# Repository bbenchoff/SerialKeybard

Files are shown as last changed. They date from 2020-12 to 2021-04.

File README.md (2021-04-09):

# Serial Keyboard

It's a keyboard that transmits serial. Or it's a 256-key keyboard, using 18 keys. Something like that. The main thing is that it transmits any serial byte.

## Notice

This repo contains a few files, but is mostly geared towards an unoptimized build with the internal structure consisting of five(!) different PCBs. The SerialKeyboard.brd is just a 18-key keyboard with diodes. The DisplayCarrier.brd is an interposer between the display and Motherboard.brd, which is the only thing with active electronics. There's also an Arduino in there and the front panel, which makes for a grand total of five different PCBs in this project.

I have started work on a simplified version, MasterBoard.brd, which would combine this all into one single circuit board. This work is not completed.

If someone can find me a source of 2U 'Transmit' keycaps, I'll get right on that.

Oh yeah, I noticed this repo was named 'SerialKeybard', but it's too late to fix it now.

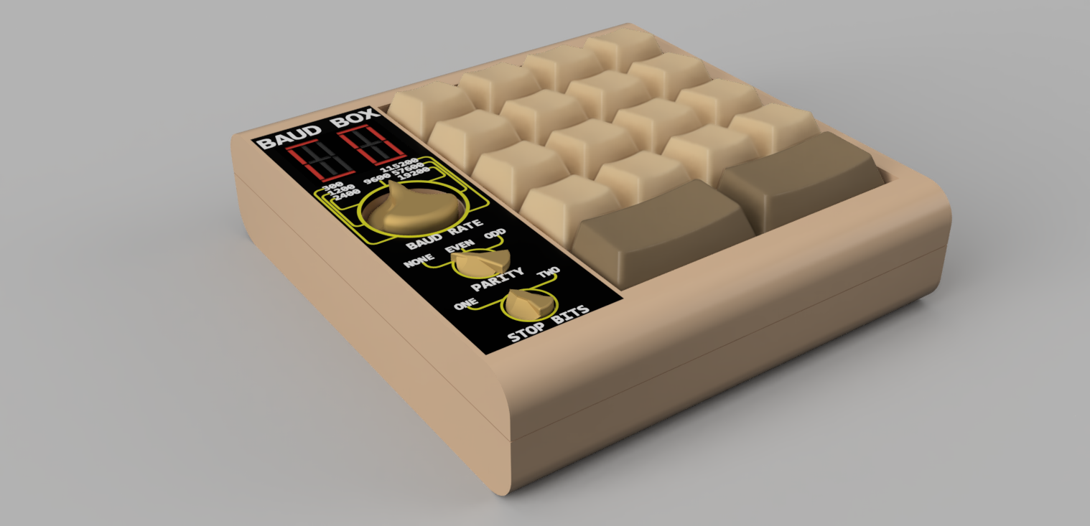
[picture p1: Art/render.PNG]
render


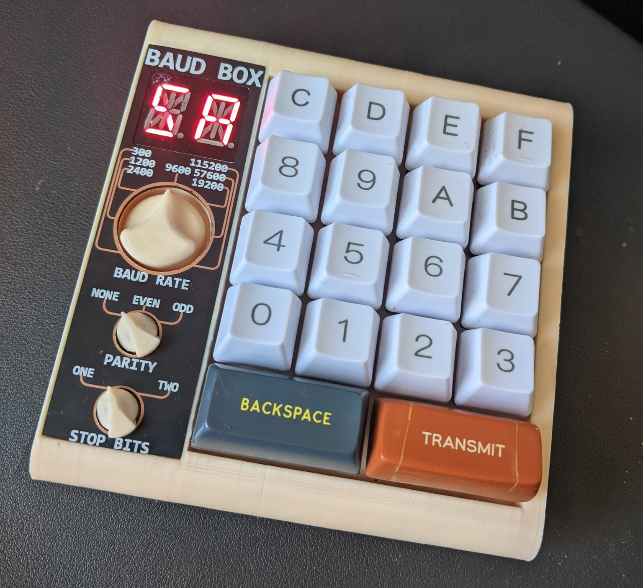
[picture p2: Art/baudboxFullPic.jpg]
full pic


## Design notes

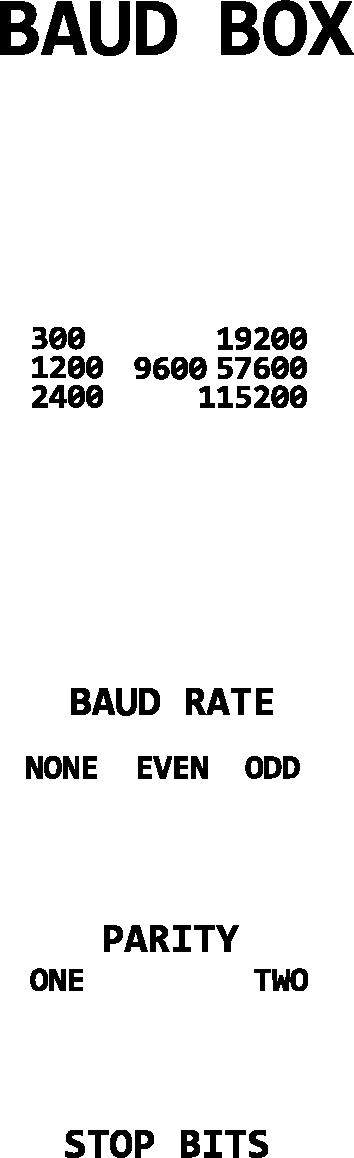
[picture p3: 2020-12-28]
Art/PanelText.bmp

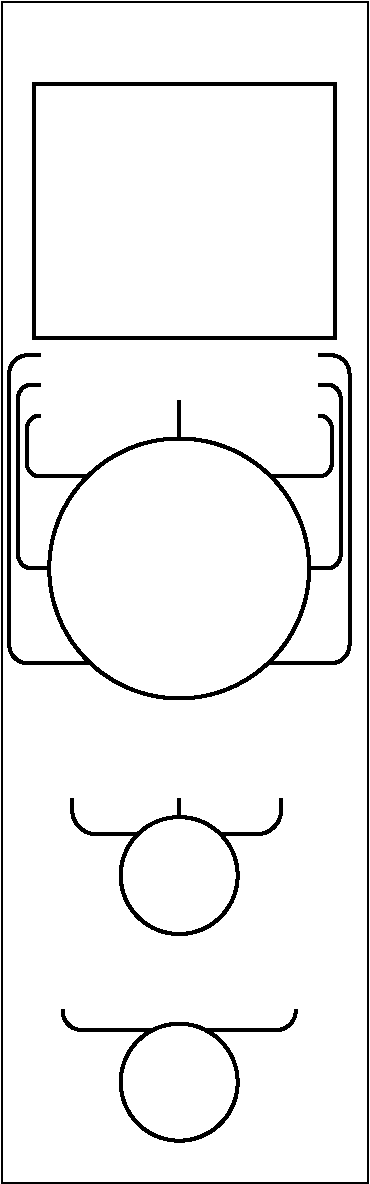
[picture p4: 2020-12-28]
Art/PanelCopper.bmp

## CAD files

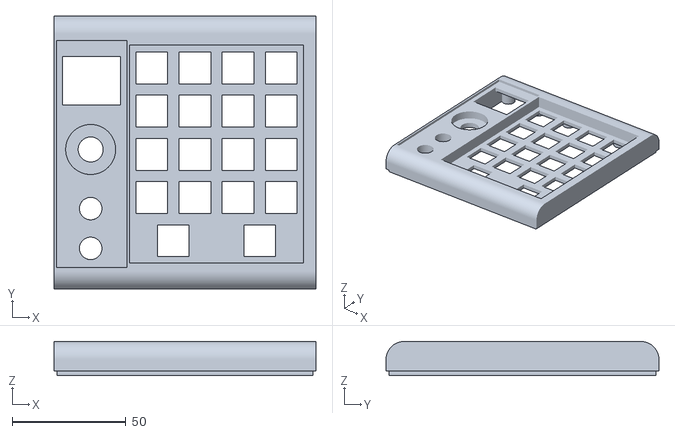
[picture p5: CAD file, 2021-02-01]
3D/Top.stl
115.2 x 120.1 x 15.0

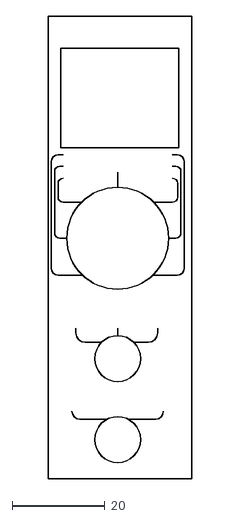
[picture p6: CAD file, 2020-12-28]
Art/PanelCopper.dxf
31.0 x 100.0

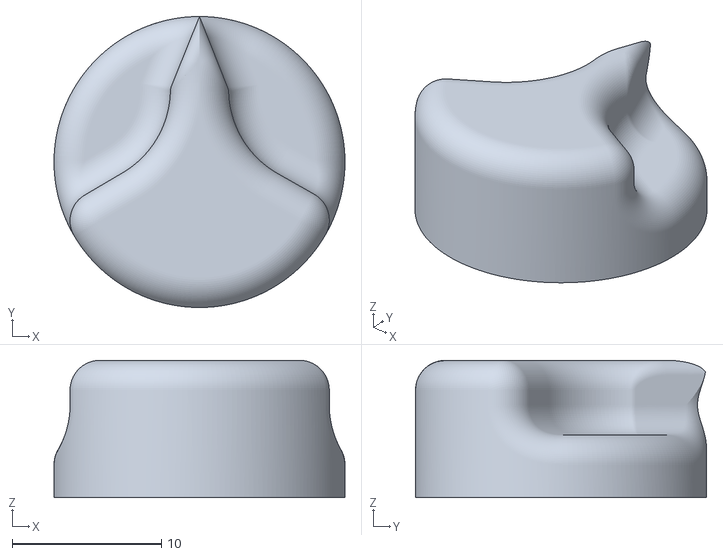
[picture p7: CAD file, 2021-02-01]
3D/BigKnob.stl
19.5 x 19.5 x 9.21

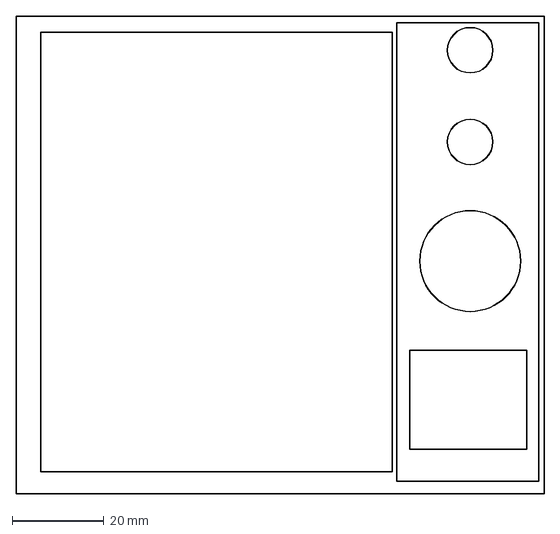
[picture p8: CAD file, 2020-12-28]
Art/PanelOutline.dxf
115.2 x 104.1 mm

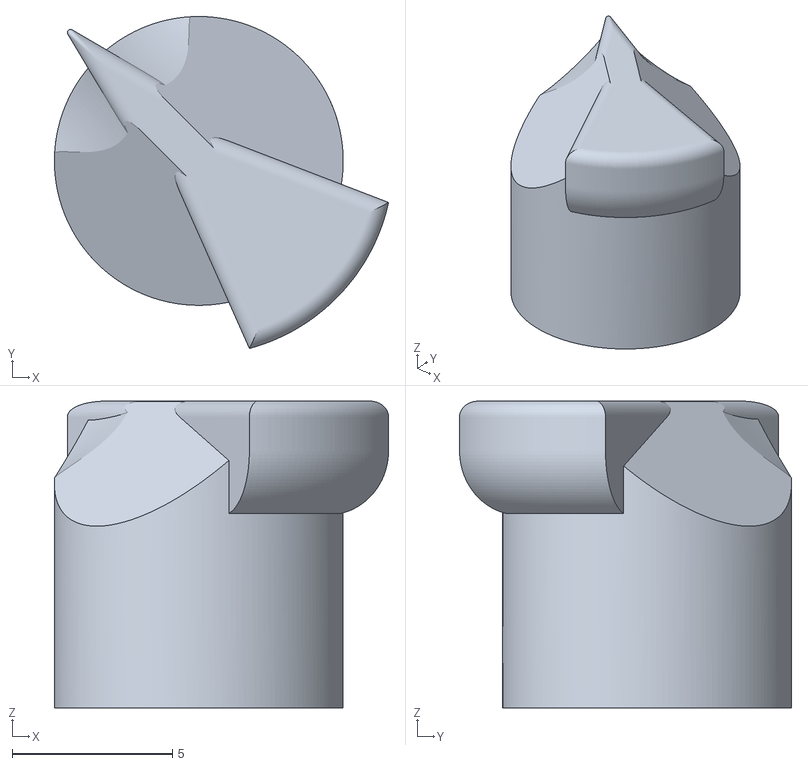
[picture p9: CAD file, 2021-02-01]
3D/SmallKnob.stl
10.4 x 10.3 x 9.57

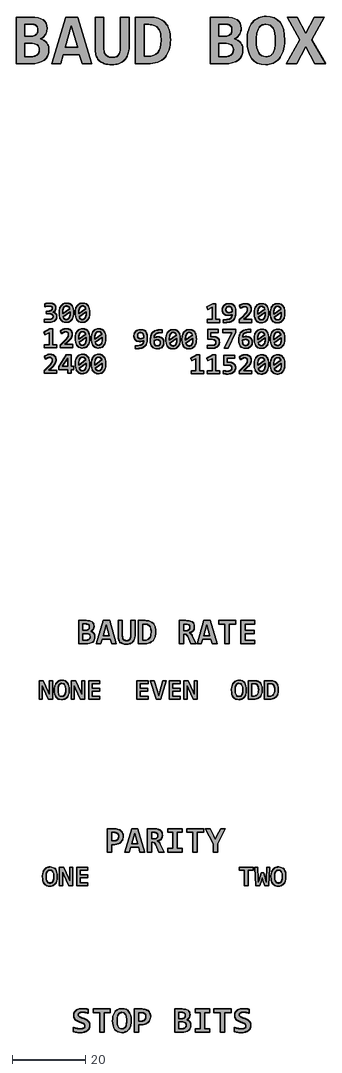
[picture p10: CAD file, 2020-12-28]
Art/PanelText.dxf
84.7 x 277.7

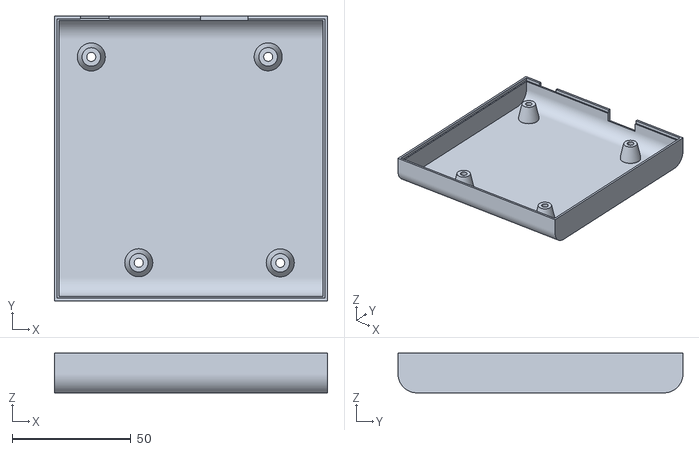
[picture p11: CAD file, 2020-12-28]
3D/Bottom.stl
115.2 x 120.1 x 16.8

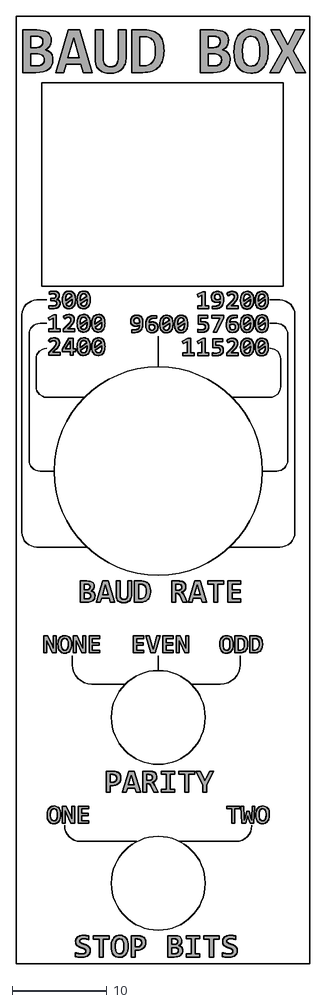
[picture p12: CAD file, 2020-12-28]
Art/FrontPanel.dxf
31.0 x 100.0

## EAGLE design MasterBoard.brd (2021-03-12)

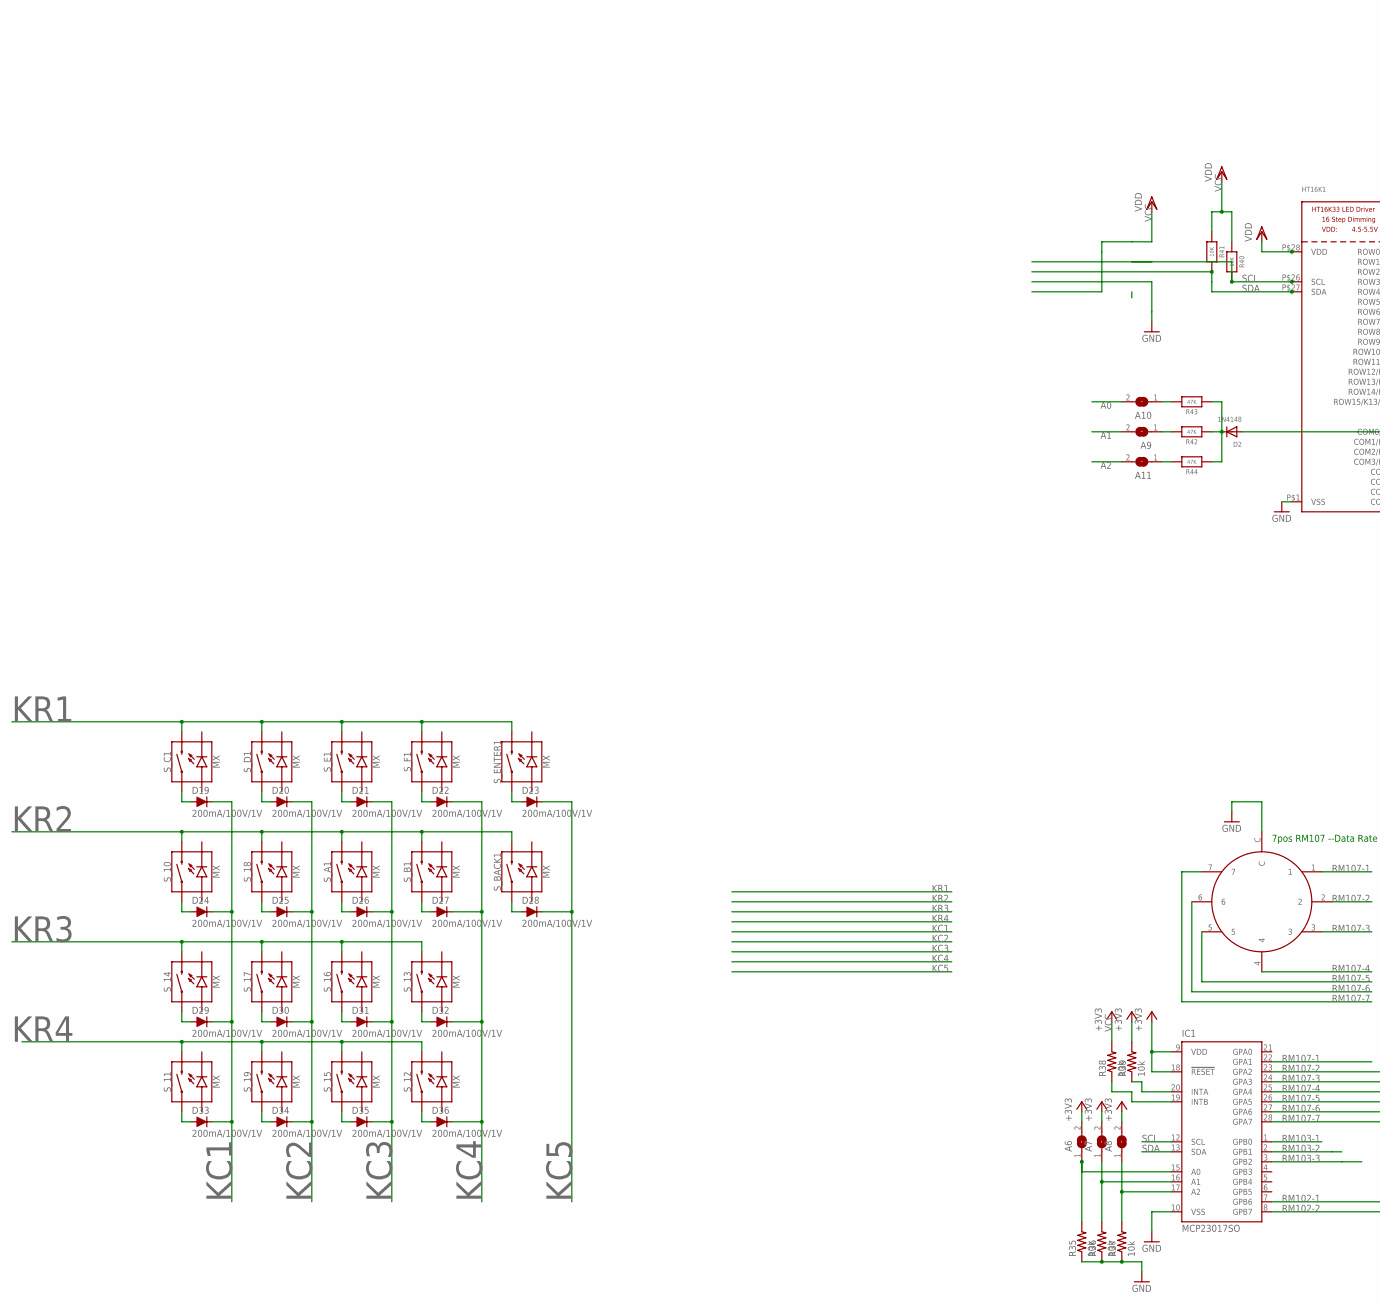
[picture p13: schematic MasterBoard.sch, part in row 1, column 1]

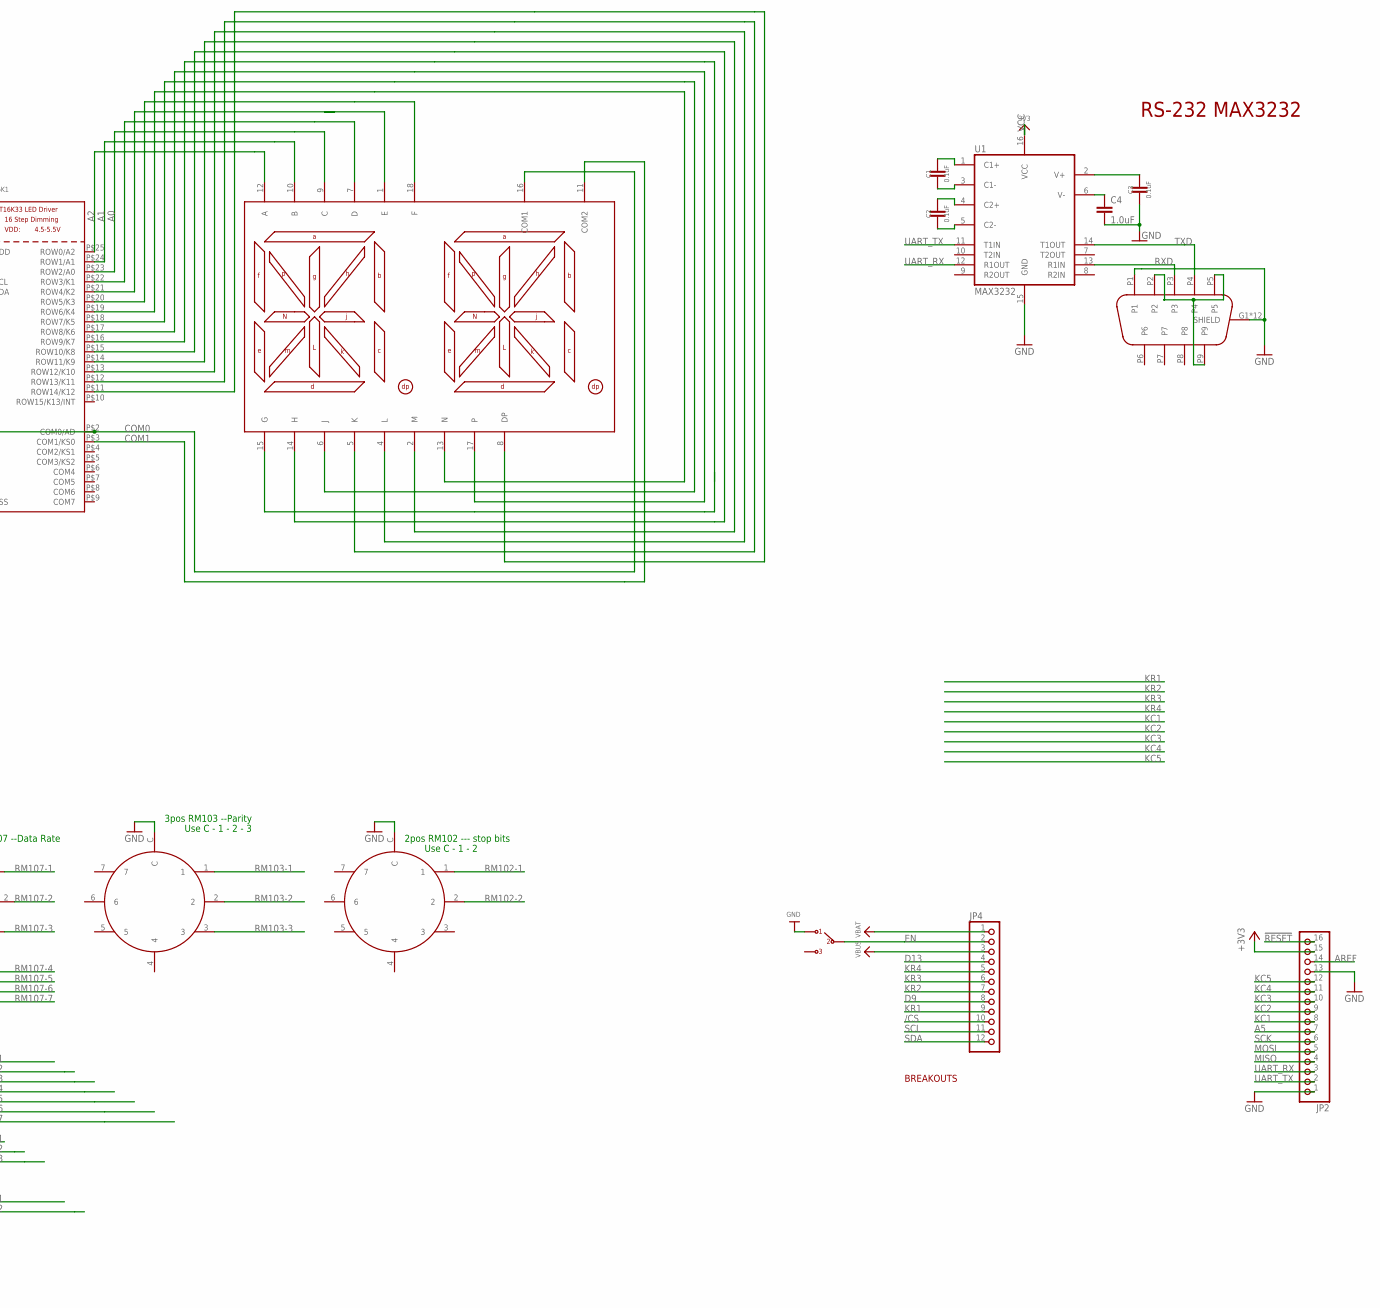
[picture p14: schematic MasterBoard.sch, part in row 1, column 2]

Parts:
A6, A7, A8: SJ
A9, A10, A11: SOLDERJUMPERREFLOW_NOPASTE; SOLDERJUMPER_REFLOW_NOPASTE
C1, C2, C3: 0.1uF; 0805
C4: 1.0uF; 0805
D2: 1N4148; SOD-323F
D19, D20, D21, D22, D23, D24, D25, D26, D27, D28, D29, D30, D31, D32, D33, D34, D35, D36: 200mA/100V/1V; DIODE-1N4148
DE9FEMALE1: EDGEMOUNTDE9; DE09S065TLF
HT16K1: HT16K33_SOP28_SKINNY; SOP28_300MIL_SKINNY
IC1: MCP23017SO; SO28W
JP2: HEADER-1X16ROUND; 1X16_ROUND
JP4: HEADER-1X12; 1X12_ROUND
R35, R36, R37, R38, R39: 10k; M0805
R40, R41: 10K; 0805-NO
R42, R43, R44: 47K; 0805-NO
S_10, S_11, S_12, S_13, S_14, S_15, S_16, S_17, S_18, S_19: MX; CHERRY-MX-LED
S_A1: MX; CHERRY-MX-LED
S_B1: MX; CHERRY-MX-LED
S_BACK1: MX; CHERRY-MX-LED
S_C1: MX; CHERRY-MX-LED
S_D1: MX; CHERRY-MX-LED
S_E1: MX; CHERRY-MX-LED
S_ENTER1: MX; CHERRY-MX-LED
S_F1: MX; CHERRY-MX-LED
U1: MAX3232; SO16
U$11: BIG14SEG; HDSP
U$12, U$17, U$18: RM107772BCB
U$15: OS102011MA1QN1

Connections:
!RESET: JP2.16
/CS: JP4.10
A0: A10.2, HT16K1.P$23 (ROW2/A0), U$11.9 (C)
A1: A9.2, HT16K1.P$24 (ROW1/A1), U$11.10 (B)
A2: A11.2, HT16K1.P$25 (ROW0/A2), U$11.12 (A)
A5: JP2.7
AREF: JP2.14
COM0: D2.A, HT16K1.P$2 (COM0/AD), U$11.16 (COM1)
COM1: HT16K1.P$3 (COM1/KS0), U$11.11 (COM2)
D9: JP4.8
D13: JP4.4
EN: JP4.2, U$15.P$2
GND: C3.2, C4.2, DE9FEMALE1.G1 (SHIELD), DE9FEMALE1.G2 (SHIELD), DE9FEMALE1.G3 (SHIELD), DE9FEMALE1.G4 (SHIELD), DE9FEMALE1.G5 (SHIELD), DE9FEMALE1.G6 (SHIELD), DE9FEMALE1.G7 (SHIELD), DE9FEMALE1.G8 (SHIELD), DE9FEMALE1.G9 (SHIELD), DE9FEMALE1.G10 (SHIELD), DE9FEMALE1.G11 (SHIELD), DE9FEMALE1.G12 (SHIELD), DE9FEMALE1.P1, HT16K1.P$1 (VSS), IC1.10 (VSS), JP2.1, JP2.13, R35.1, R36.1, R37.1, U1.15 (GND), U$12.C, U$15.P$1, U$17.C, U$18.C
KC1: D19.C, D24.C, D29.C, D33.C, JP2.8
KC2: D20.C, D25.C, D30.C, D34.C, JP2.9
KC3: D21.C, D26.C, D31.C, D35.C, JP2.10
KC4: D22.C, D27.C, D32.C, D36.C, JP2.11
KC5: D23.C, D28.C, JP2.12
KR1: JP4.9, S_C1.S2 (2), S_D1.S2 (2), S_E1.S2 (2), S_ENTER1.S2 (2), S_F1.S2 (2)
KR2: JP4.7, S_10.S2 (2), S_18.S2 (2), S_A1.S2 (2), S_B1.S2 (2), S_BACK1.S2 (2)
KR3: JP4.6, S_13.S2 (2), S_14.S2 (2), S_16.S2 (2), S_17.S2 (2)
KR4: JP4.5, S_11.S2 (2), S_12.S2 (2), S_15.S2 (2), S_19.S2 (2)
MISO: JP2.4
MOSI: JP2.5
unnamed: D33.A, S_11.S1 (1)
unnamed: D34.A, S_19.S1 (1)
unnamed: D35.A, S_15.S1 (1)
unnamed: D36.A, S_12.S1 (1)
unnamed: D29.A, S_14.S1 (1)
unnamed: D30.A, S_17.S1 (1)
unnamed: D31.A, S_16.S1 (1)
unnamed: D32.A, S_13.S1 (1)
unnamed: D24.A, S_10.S1 (1)
unnamed: D25.A, S_18.S1 (1)
unnamed: D26.A, S_A1.S1 (1)
unnamed: D27.A, S_B1.S1 (1)
unnamed: D28.A, S_BACK1.S1 (1)
unnamed: D23.A, S_ENTER1.S1 (1)
unnamed: D22.A, S_F1.S1 (1)
unnamed: D21.A, S_E1.S1 (1)
unnamed: D20.A, S_D1.S1 (1)
unnamed: D19.A, S_C1.S1 (1)
unnamed: C1.2, U1.3 (C1-)
unnamed: C1.1, U1.1 (C1+)
unnamed: C2.1, U1.4 (C2+)
unnamed: C2.2, U1.5 (C2-)
unnamed: C3.1, U1.2 (V+)
unnamed: C4.1, U1.6 (V-)
unnamed: DE9FEMALE1.P2, DE9FEMALE1.P5, DE9FEMALE1.P9
unnamed: A6.1, IC1.15 (A0), R35.2
unnamed: A7.1, IC1.16 (A1), R36.2
unnamed: A8.1, IC1.17 (A2), R37.2
unnamed: IC1.19 (INTB), R38.1
unnamed: IC1.20 (INTA), R39.1
unnamed: A9.1, R42.2
unnamed: A10.1, R43.2
unnamed: HT16K1.P$22 (ROW3/K1), U$11.7 (D)
unnamed: HT16K1.P$21 (ROW4/K2), U$11.1 (E)
unnamed: HT16K1.P$20 (ROW5/K3), U$11.18 (F)
unnamed: HT16K1.P$19 (ROW6/K4), U$11.13 (N)
unnamed: HT16K1.P$18 (ROW7/K5), U$11.6 (J)
unnamed: D2.C, R42.1, R43.1, R44.1
unnamed: A11.1, R44.2
unnamed: HT16K1.P$17 (ROW8/K6), U$11.17
unnamed: HT16K1.P$16 (ROW9/K7), U$11.15 (G)
unnamed: HT16K1.P$15 (ROW10/K8), U$11.14 (H)
unnamed: HT16K1.P$14 (ROW11/K9), U$11.2 (M)
unnamed: HT16K1.P$13 (ROW12/K10), U$11.4 (L)
unnamed: HT16K1.P$12 (ROW13/K11), U$11.5 (K)
unnamed: HT16K1.P$11 (ROW14/K12), U$11.8 (DP)
RM102-1: IC1.7 (GPB6), U$18.1
RM102-2: IC1.8 (GPB7), U$18.2
RM103-1: IC1.1 (GPB0), U$17.1
RM103-2: IC1.2 (GPB1), U$17.2
RM103-3: IC1.3 (GPB2), U$17.3
RM107-1: IC1.22 (GPA1), U$12.1
RM107-2: IC1.23 (GPA2), U$12.2
RM107-3: IC1.24 (GPA3), U$12.3
RM107-4: IC1.25 (GPA4), U$12.4
RM107-5: IC1.26 (GPA5), U$12.5
RM107-6: IC1.27 (GPA6), U$12.6
RM107-7: IC1.28 (GPA7), U$12.7
RXD: DE9FEMALE1.P3, U1.13 (R1IN)
SCK: JP2.6
SCL: HT16K1.P$26 (SCL), IC1.12 (SCL), JP4.11, R40.2
SDA: HT16K1.P$27 (SDA), IC1.13 (SDA), JP4.12, R41.2
TXD: DE9FEMALE1.P4, U1.14 (T1OUT)
UART_RX: JP2.3, U1.12 (R1OUT)
UART_TX: JP2.2, U1.11 (T1IN)
VBAT: JP4.1
VBUS: JP4.3
VCC: A6.2, A7.2, A8.2, HT16K1.P$28 (VDD), IC1.9 (VDD), IC1.18 (!RESET), JP2.15, R38.2, R39.2, R40.1, R41.1, U1.16 (VCC)

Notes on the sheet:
RS-232 MAX3232
7pos RM107 --Data Rate
3pos RM103 --Parity
Use C - 1 - 2 - 3
2pos RM102 --- stop bits
Use C - 1 - 2
BREAKOUTS

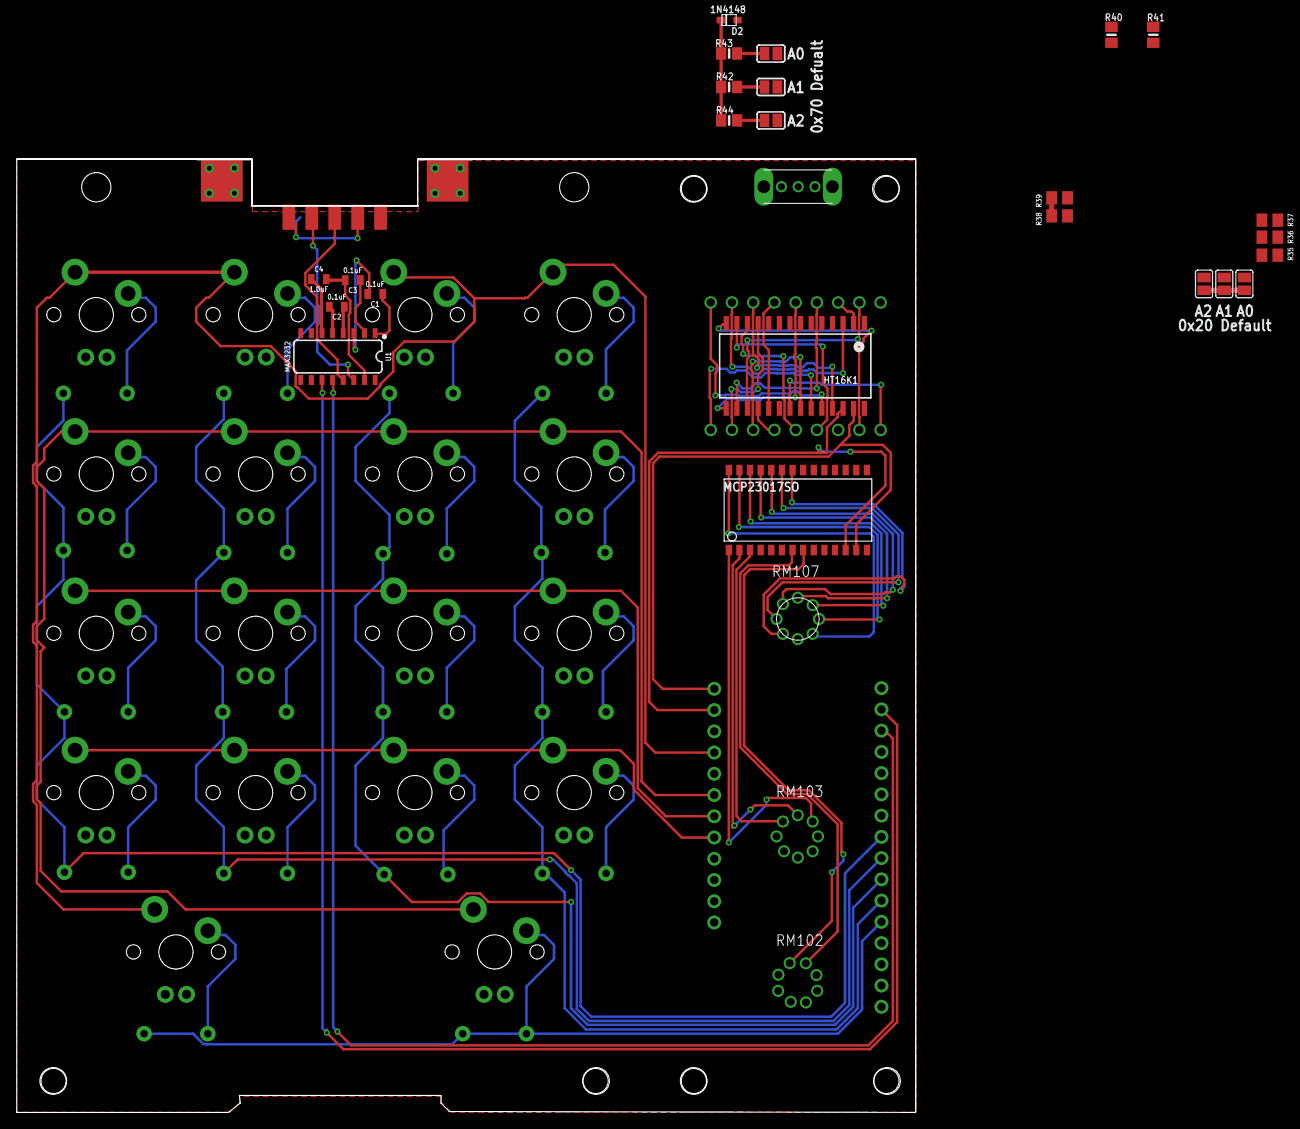
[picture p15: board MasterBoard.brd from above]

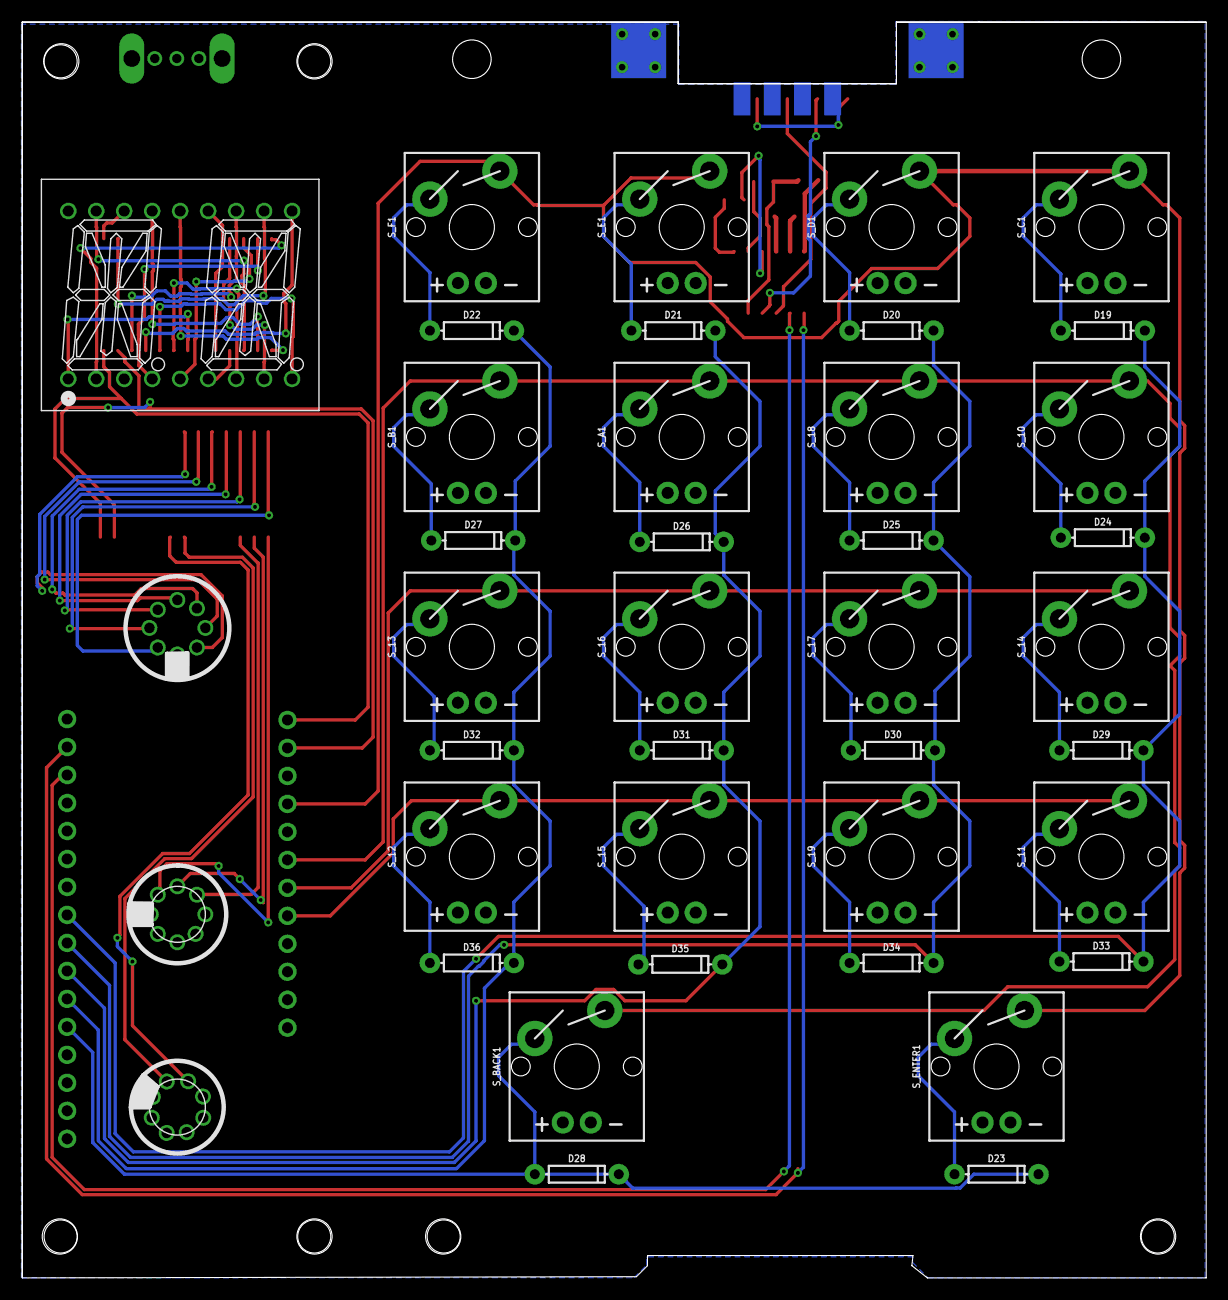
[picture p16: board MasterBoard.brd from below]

Board: 2 copper layers, 107.5 x 114.0 mm, 68 parts (39 on the bottom side), 81 nets.

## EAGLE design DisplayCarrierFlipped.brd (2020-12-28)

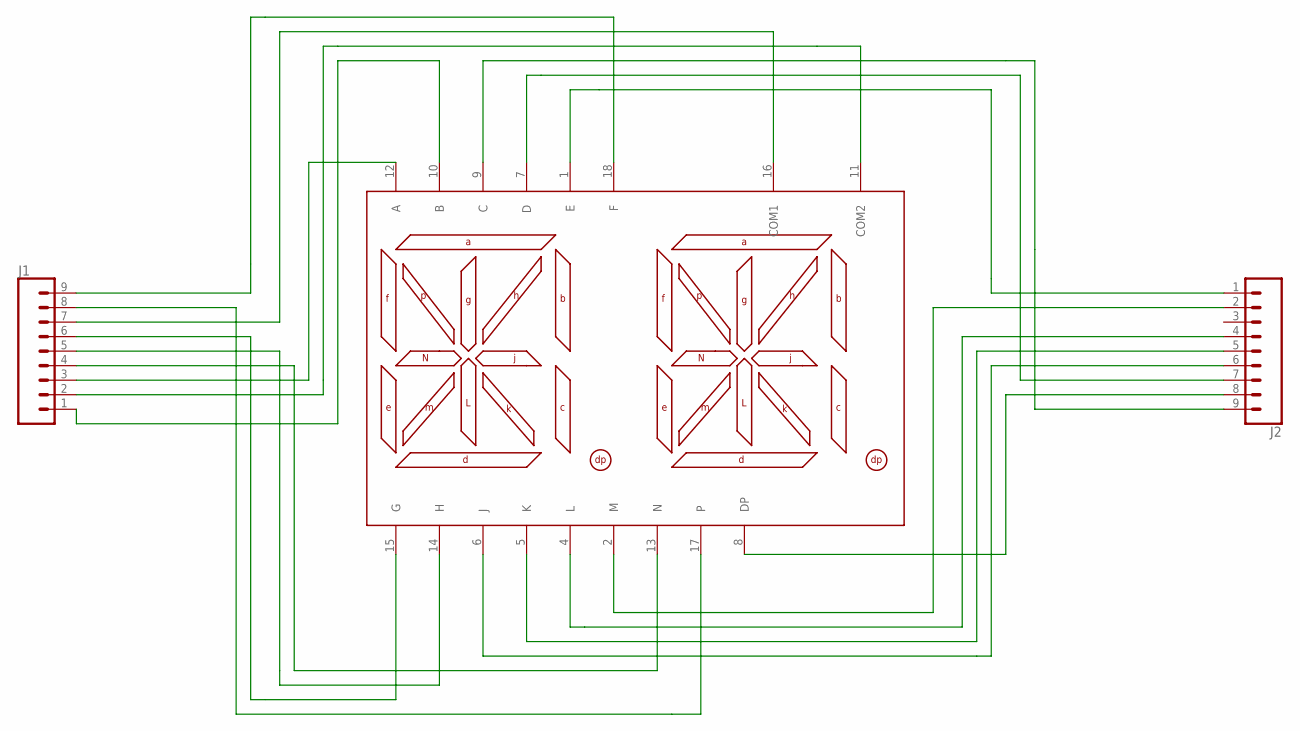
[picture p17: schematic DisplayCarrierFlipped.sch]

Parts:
J1, J2: CONN_09; 1X09
U$1: HDSP-A27C; DIP-18

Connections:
unnamed: J2.1, U$1.1 (E)
unnamed: J1.1, U$1.10 (B)
unnamed: J1.2, U$1.11 (COM2)
unnamed: J1.3, U$1.12 (A)
unnamed: J1.4, U$1.13 (N)
unnamed: J1.5, U$1.14 (H)
unnamed: J1.6, U$1.15 (G)
unnamed: J1.7, U$1.16 (COM1)
unnamed: J1.8, U$1.17
unnamed: J2.2, U$1.2 (M)
unnamed: J2.4, U$1.4 (L)
unnamed: J2.5, U$1.5 (K)
unnamed: J2.6, U$1.6 (J)
unnamed: J2.7, U$1.7 (D)
unnamed: J2.8, U$1.8 (DP)
unnamed: J1.9, U$1.18 (F)
unnamed: J2.9, U$1.9 (C)

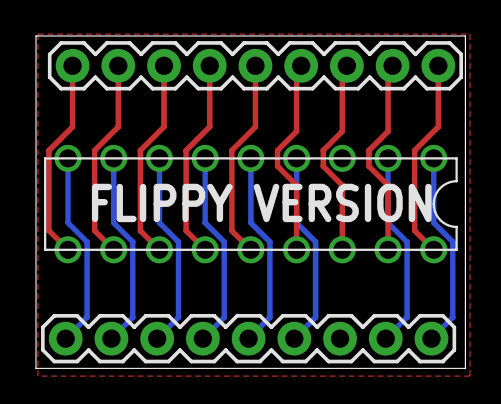
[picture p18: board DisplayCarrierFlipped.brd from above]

Board: 2 copper layers, 23.9 x 18.5 mm, 3 parts (0 on the bottom side), 17 nets.

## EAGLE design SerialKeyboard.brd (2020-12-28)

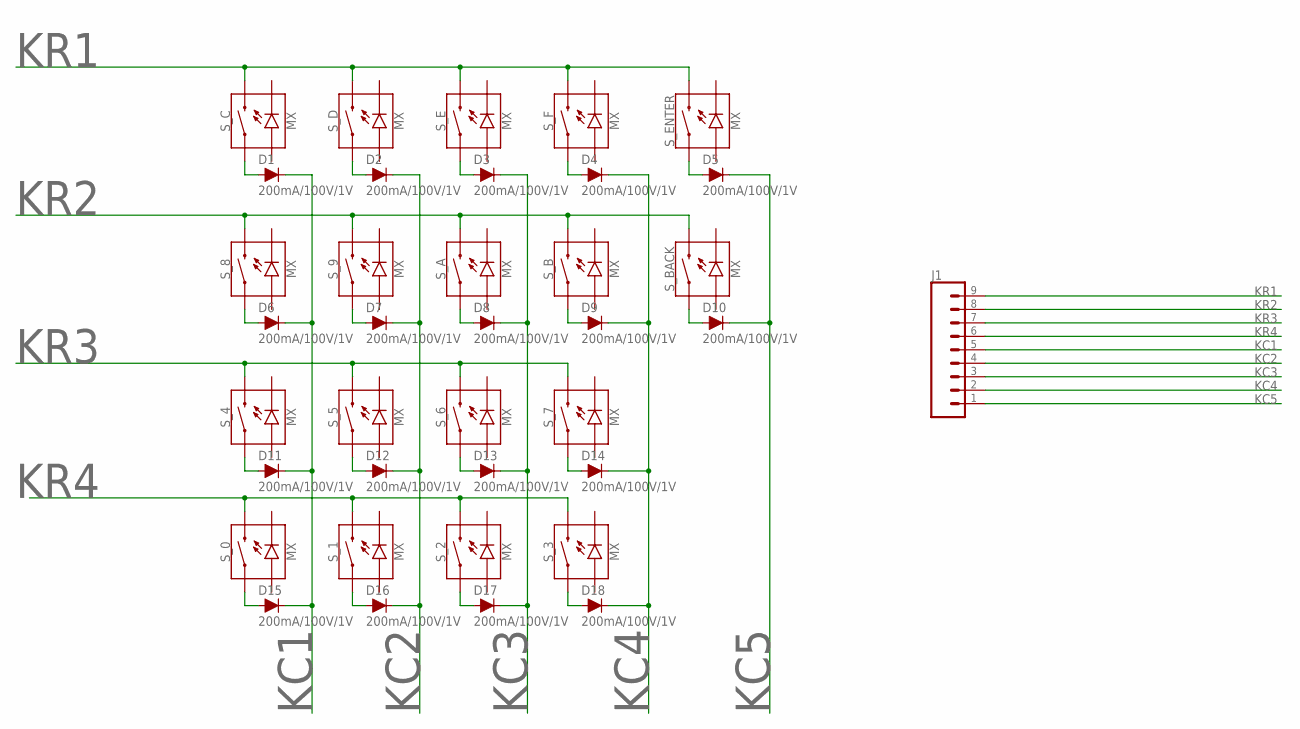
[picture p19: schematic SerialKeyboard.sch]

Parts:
D1, D2, D3, D4, D5, D6, D7, D8, D9, D10, D11, D12, D13, D14, D15, D16, D17, D18: 200mA/100V/1V; DIODE-1N4148
J1: CONN_09; 1X09
S_0, S_1, S_2, S_3, S_4, S_5, S_6, S_7, S_8, S_9: MX; CHERRY-MX-LED
S_A: MX; CHERRY-MX-LED
S_B: MX; CHERRY-MX-LED
S_BACK: MX; CHERRY-MX-LED
S_C: MX; CHERRY-MX-LED
S_D: MX; CHERRY-MX-LED
S_E: MX; CHERRY-MX-LED
S_ENTER: MX; CHERRY-MX-LED
S_F: MX; CHERRY-MX-LED

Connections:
KC1: D1.C, D6.C, D11.C, D15.C, J1.5
KC2: D2.C, D7.C, D12.C, D16.C, J1.4
KC3: D3.C, D8.C, D13.C, D17.C, J1.3
KC4: D4.C, D9.C, D14.C, D18.C, J1.2
KC5: D5.C, D10.C, J1.1
KR1: J1.9, S_C.S2 (2), S_D.S2 (2), S_E.S2 (2), S_ENTER.S2 (2), S_F.S2 (2)
KR2: J1.8, S_8.S2 (2), S_9.S2 (2), S_A.S2 (2), S_B.S2 (2), S_BACK.S2 (2)
KR3: J1.7, S_4.S2 (2), S_5.S2 (2), S_6.S2 (2), S_7.S2 (2)
KR4: J1.6, S_0.S2 (2), S_1.S2 (2), S_2.S2 (2), S_3.S2 (2)
unnamed: D15.A, S_0.S1 (1)
unnamed: D16.A, S_1.S1 (1)
unnamed: D17.A, S_2.S1 (1)
unnamed: D18.A, S_3.S1 (1)
unnamed: D11.A, S_4.S1 (1)
unnamed: D12.A, S_5.S1 (1)
unnamed: D13.A, S_6.S1 (1)
unnamed: D14.A, S_7.S1 (1)
unnamed: D6.A, S_8.S1 (1)
unnamed: D7.A, S_9.S1 (1)
unnamed: D8.A, S_A.S1 (1)
unnamed: D9.A, S_B.S1 (1)
unnamed: D10.A, S_BACK.S1 (1)
unnamed: D5.A, S_ENTER.S1 (1)
unnamed: D4.A, S_F.S1 (1)
unnamed: D3.A, S_E.S1 (1)
unnamed: D2.A, S_D.S1 (1)
unnamed: D1.A, S_C.S1 (1)

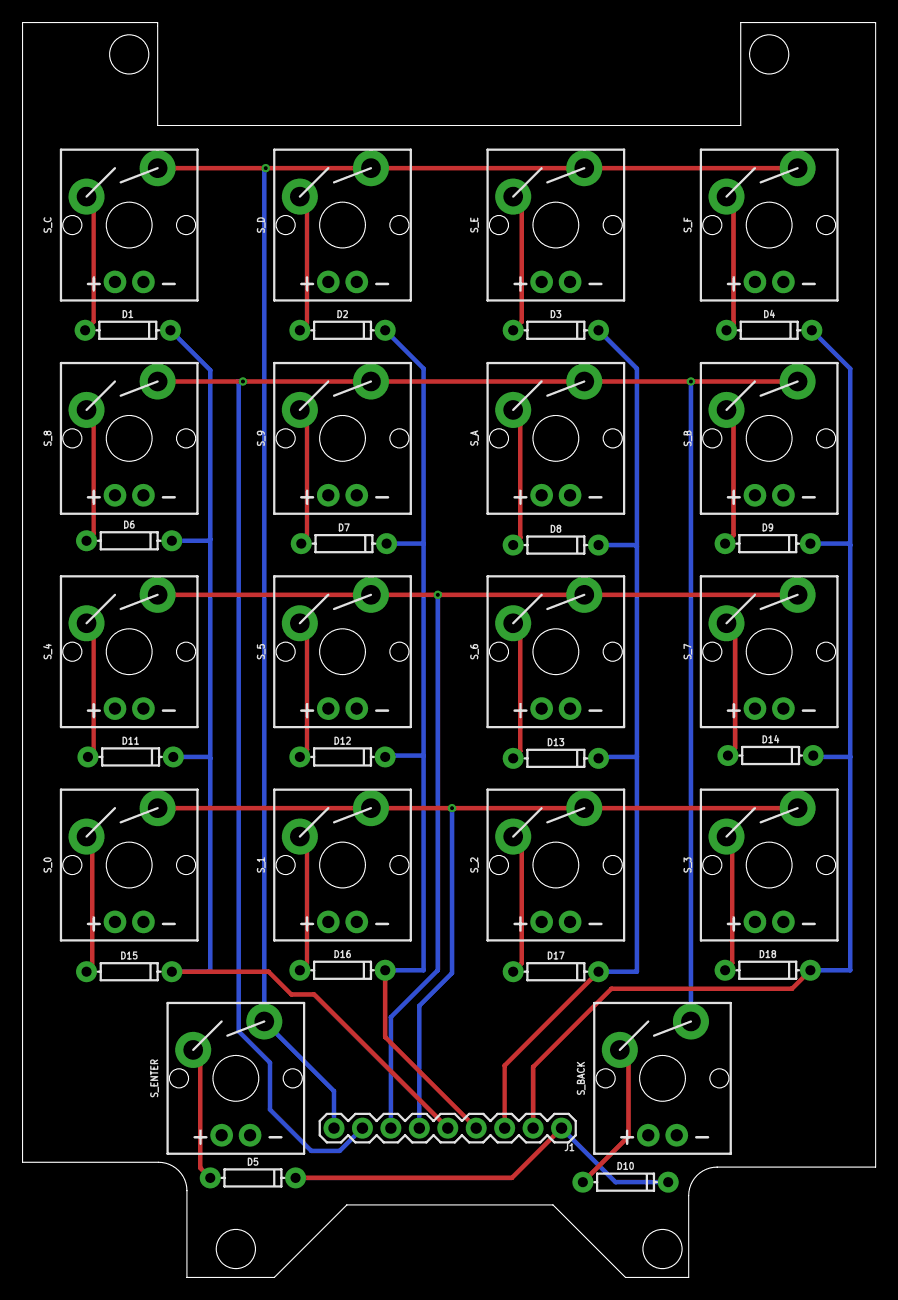
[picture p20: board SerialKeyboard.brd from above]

Board: 2 copper layers, 76.2 x 112.1 mm, 37 parts (0 on the bottom side), 27 nets.

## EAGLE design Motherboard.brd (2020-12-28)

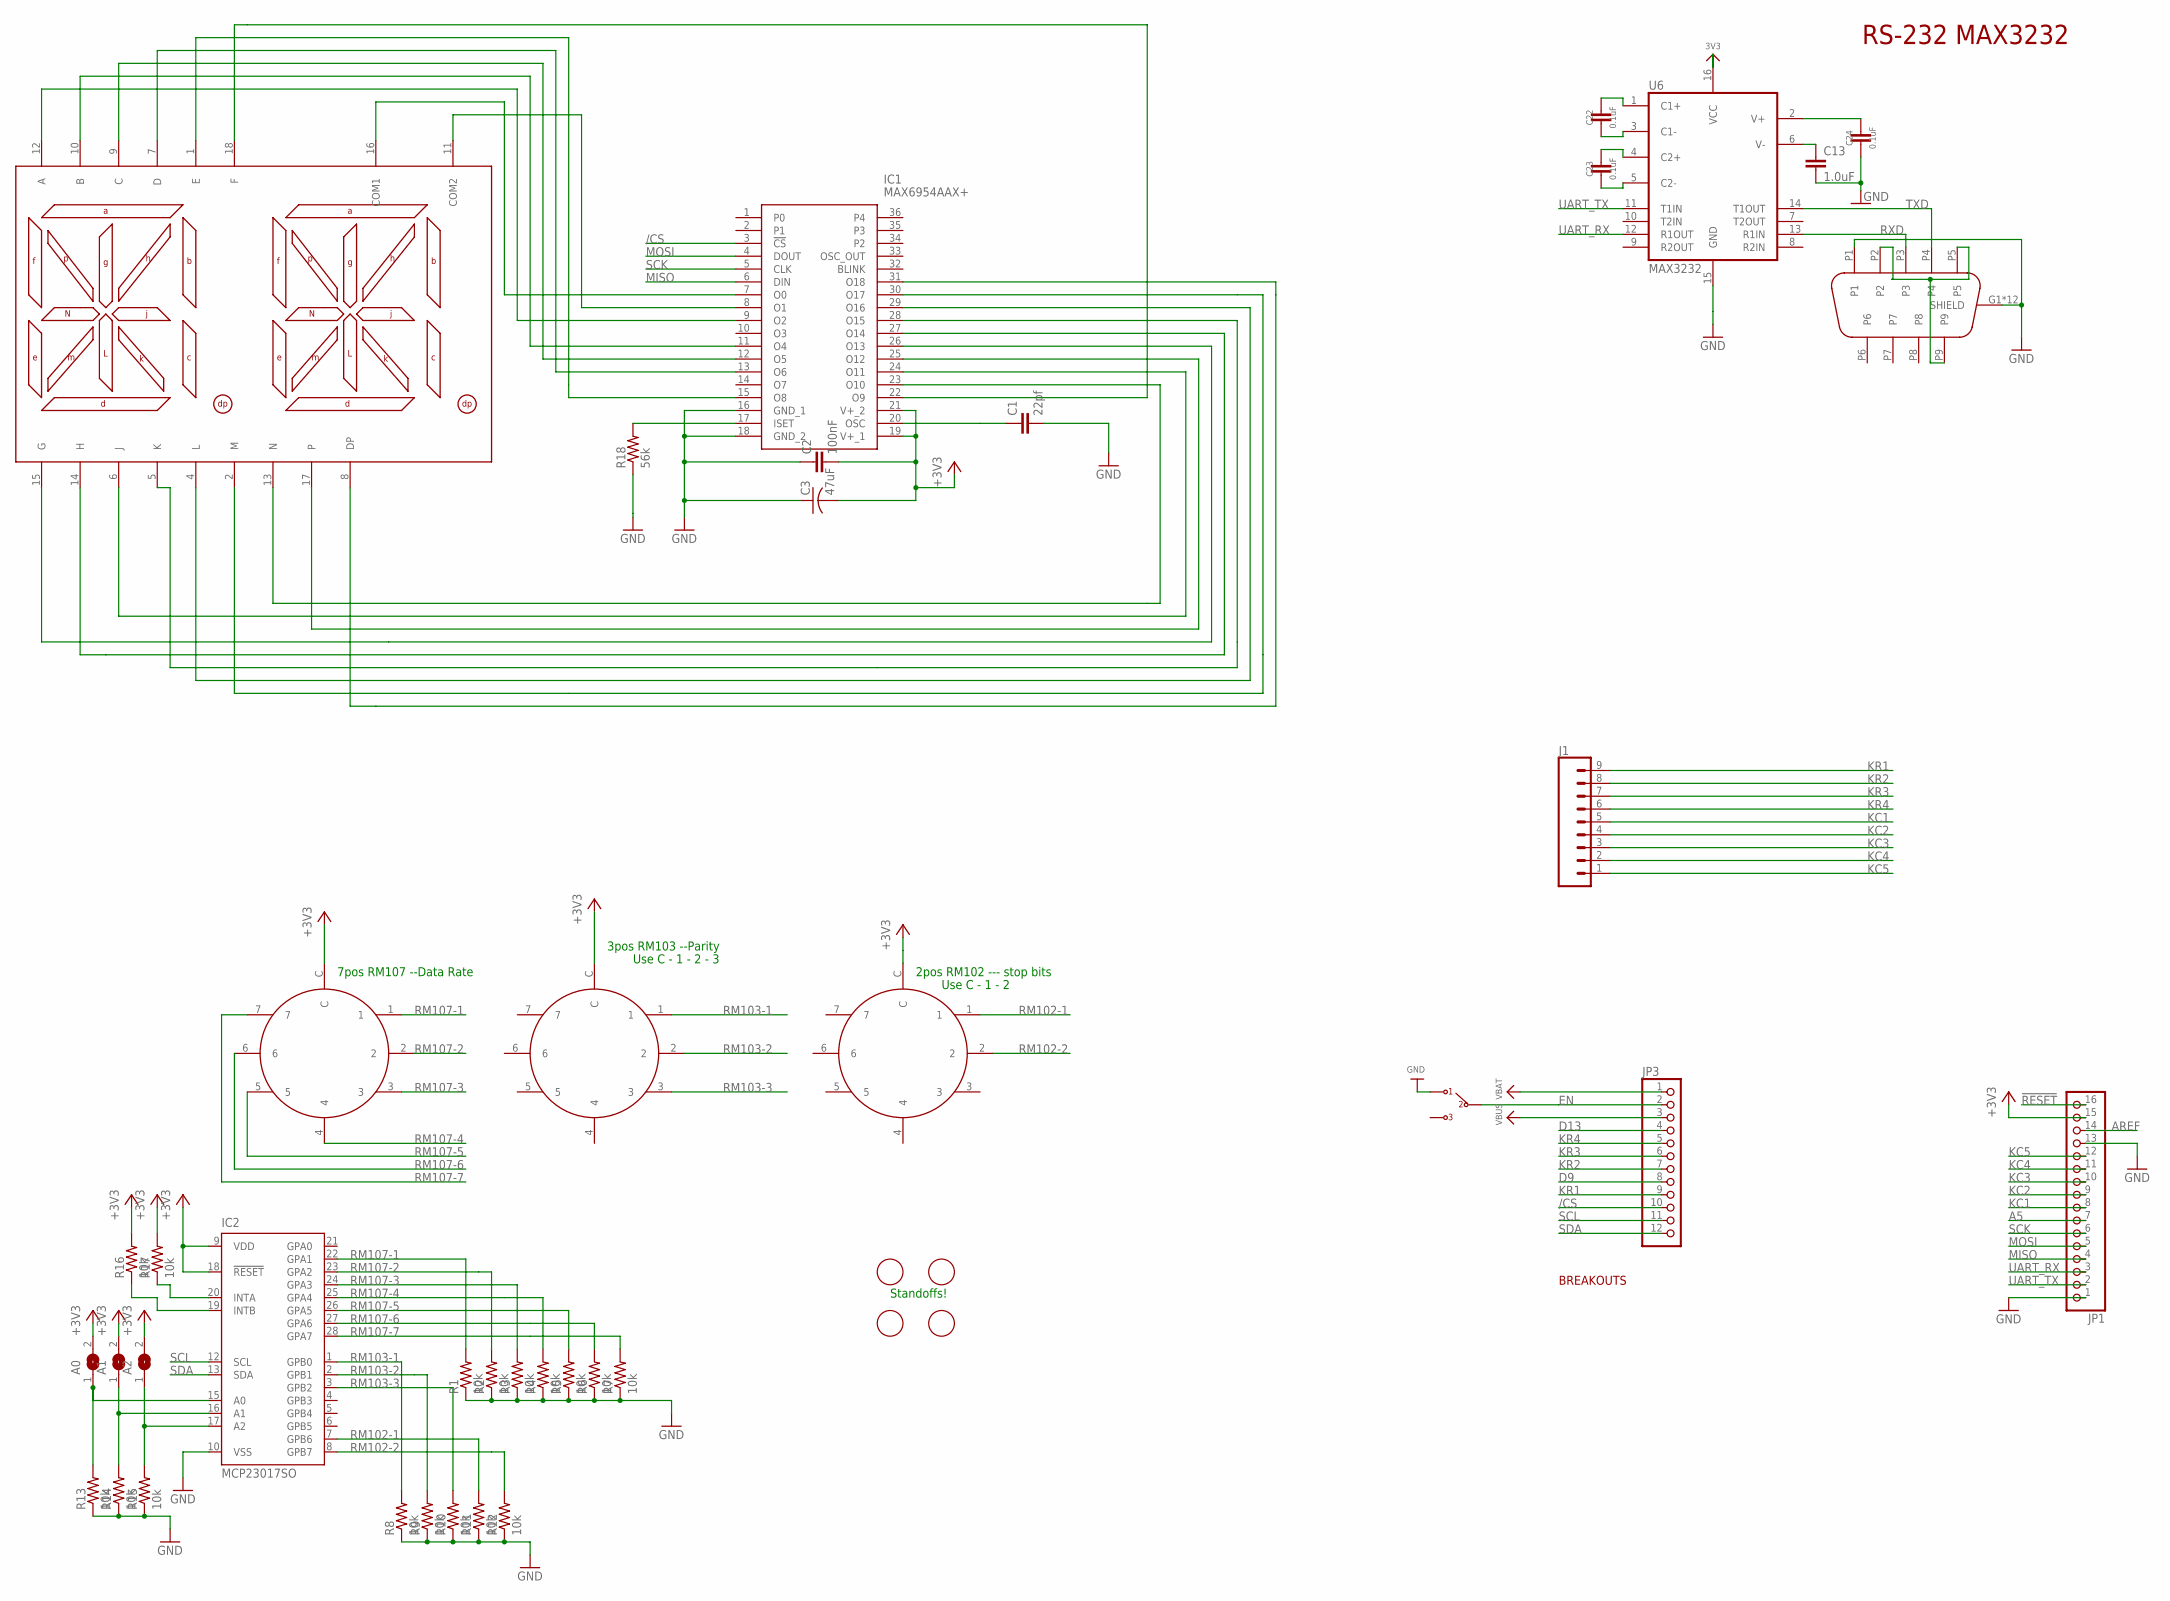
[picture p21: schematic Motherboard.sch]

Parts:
A0, A1, A2: SJ
C1: 22pf; 0805
C2: 100nF; 0805
C3: 47uF; C1206
C13: 1.0uF; 0805
C22, C23, C24: 0.1uF; 0805
DE9FEMALE: EDGEMOUNTDE9; DE09S065TLF
IC1: MAX6954AAX+; SOP80P1030X264-36N
IC2: MCP23017SO; SO28W
J1: CONN_09; 1X09
JP1: HEADER-1X16ROUND; 1X16_ROUND
JP3: HEADER-1X12; 1X12_ROUND
R1, R2, R3, R4, R5, R6, R7, R8, R9, R10, R11, R12, R13, R14, R15, R16, R17: 10k; M0805
R18: 56k; M0805
U6: MAX3232; SO16
U$1: HDSP-A27C; DIP-18
U$2, U$3, U$6: RM107772BCB
U$5: OS102011MA1QN1
U$7, U$8, U$9, U$10: KEYSTONESTANDOFF

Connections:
3V3: U6.16 (VCC)
!RESET: JP1.16
+3V3: A0.2, A1.2, A2.2, C2.2, C3.2, IC1.19 (V+_1), IC1.21 (V+_2), IC2.9 (VDD), IC2.18 (!RESET), JP1.15, R16.2, R17.2, U$2.C, U$3.C, U$6.C
/CS: IC1.3 (!CS), JP3.10
A5: JP1.7
AREF: JP1.14
D9: JP3.8
D13: JP3.4
EN: JP3.2, U$5.P$2
GND: C1.2, C2.1, C3.1, C13.2, C24.2, DE9FEMALE.G1 (SHIELD), DE9FEMALE.G2 (SHIELD), DE9FEMALE.G3 (SHIELD), DE9FEMALE.G4 (SHIELD), DE9FEMALE.G5 (SHIELD), DE9FEMALE.G6 (SHIELD), DE9FEMALE.G7 (SHIELD), DE9FEMALE.G8 (SHIELD), DE9FEMALE.G9 (SHIELD), DE9FEMALE.G10 (SHIELD), DE9FEMALE.G11 (SHIELD), DE9FEMALE.G12 (SHIELD), DE9FEMALE.P1, IC1.16 (GND_1), IC1.18 (GND_2), IC2.10 (VSS), JP1.1, JP1.13, R1.1, R2.1, R3.1, R4.1, R5.1, R6.1, R7.1, R8.1, R9.1, R10.1, R11.1, R12.1, R13.1, R14.1, R15.1, R18.1, U6.15 (GND), U$5.P$1
KC1: J1.5, JP1.8
KC2: J1.4, JP1.9
KC3: J1.3, JP1.10
KC4: J1.2, JP1.11
KC5: J1.1, JP1.12
KR1: J1.9, JP3.9
KR2: J1.8, JP3.7
KR3: J1.7, JP3.6
KR4: J1.6, JP3.5
MISO: IC1.6 (DIN), JP1.4
MOSI: IC1.4 (DOUT), JP1.5
unnamed: IC1.7 (O0), U$1.16 (COM1)
unnamed: IC1.9 (O2), U$1.12 (A)
unnamed: IC1.11 (O4), U$1.10 (B)
unnamed: IC1.12 (O5), U$1.9 (C)
unnamed: IC1.13 (O6), U$1.7 (D)
unnamed: IC1.15 (O8), U$1.1 (E)
unnamed: IC1.22 (O9), U$1.18 (F)
unnamed: IC1.23 (O10), U$1.13 (N)
unnamed: IC1.24 (O11), U$1.6 (J)
unnamed: IC1.25 (O12), U$1.17
unnamed: IC1.26 (O13), U$1.15 (G)
unnamed: IC1.27 (O14), U$1.14 (H)
unnamed: IC1.28 (O15), U$1.5 (K)
unnamed: IC1.29 (O16), U$1.4 (L)
unnamed: IC1.30 (O17), U$1.2 (M)
unnamed: IC1.31 (O18), U$1.8 (DP)
unnamed: IC1.8 (O1), U$1.11 (COM2)
unnamed: C22.2, U6.3 (C1-)
unnamed: C22.1, U6.1 (C1+)
unnamed: C23.1, U6.4 (C2+)
unnamed: C23.2, U6.5 (C2-)
unnamed: C24.1, U6.2 (V+)
unnamed: C13.1, U6.6 (V-)
unnamed: DE9FEMALE.P2, DE9FEMALE.P5, DE9FEMALE.P9
unnamed: A0.1, IC2.15 (A0), R13.2
unnamed: A1.1, IC2.16 (A1), R14.2
unnamed: A2.1, IC2.17 (A2), R15.2
unnamed: IC2.19 (INTB), R16.1
unnamed: IC2.20 (INTA), R17.1
unnamed: C1.1, IC1.20 (OSC)
unnamed: IC1.17 (ISET), R18.2
RM102-1: IC2.7 (GPB6), R11.2, U$6.1
RM102-2: IC2.8 (GPB7), R12.2, U$6.2
RM103-1: IC2.1 (GPB0), R8.2, U$3.1
RM103-2: IC2.2 (GPB1), R9.2, U$3.2
RM103-3: IC2.3 (GPB2), R10.2, U$3.3
RM107-1: IC2.22 (GPA1), R1.2, U$2.1
RM107-2: IC2.23 (GPA2), R2.2, U$2.2
RM107-3: IC2.24 (GPA3), R3.2, U$2.3
RM107-4: IC2.25 (GPA4), R4.2, U$2.4
RM107-5: IC2.26 (GPA5), R5.2, U$2.5
RM107-6: IC2.27 (GPA6), R6.2, U$2.6
RM107-7: IC2.28 (GPA7), R7.2, U$2.7
RXD: DE9FEMALE.P3, U6.13 (R1IN)
SCK: IC1.5 (CLK), JP1.6
SCL: IC2.12 (SCL), JP3.11
SDA: IC2.13 (SDA), JP3.12
TXD: DE9FEMALE.P4, U6.14 (T1OUT)
UART_RX: JP1.3, U6.12 (R1OUT)
UART_TX: JP1.2, U6.11 (T1IN)
VBAT: JP3.1
VBUS: JP3.3

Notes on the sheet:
RS-232 MAX3232
7pos RM107 --Data Rate
3pos RM103 --Parity
Use C - 1 - 2 - 3
2pos RM102 --- stop bits
Use C - 1 - 2
BREAKOUTS
Standoffs!

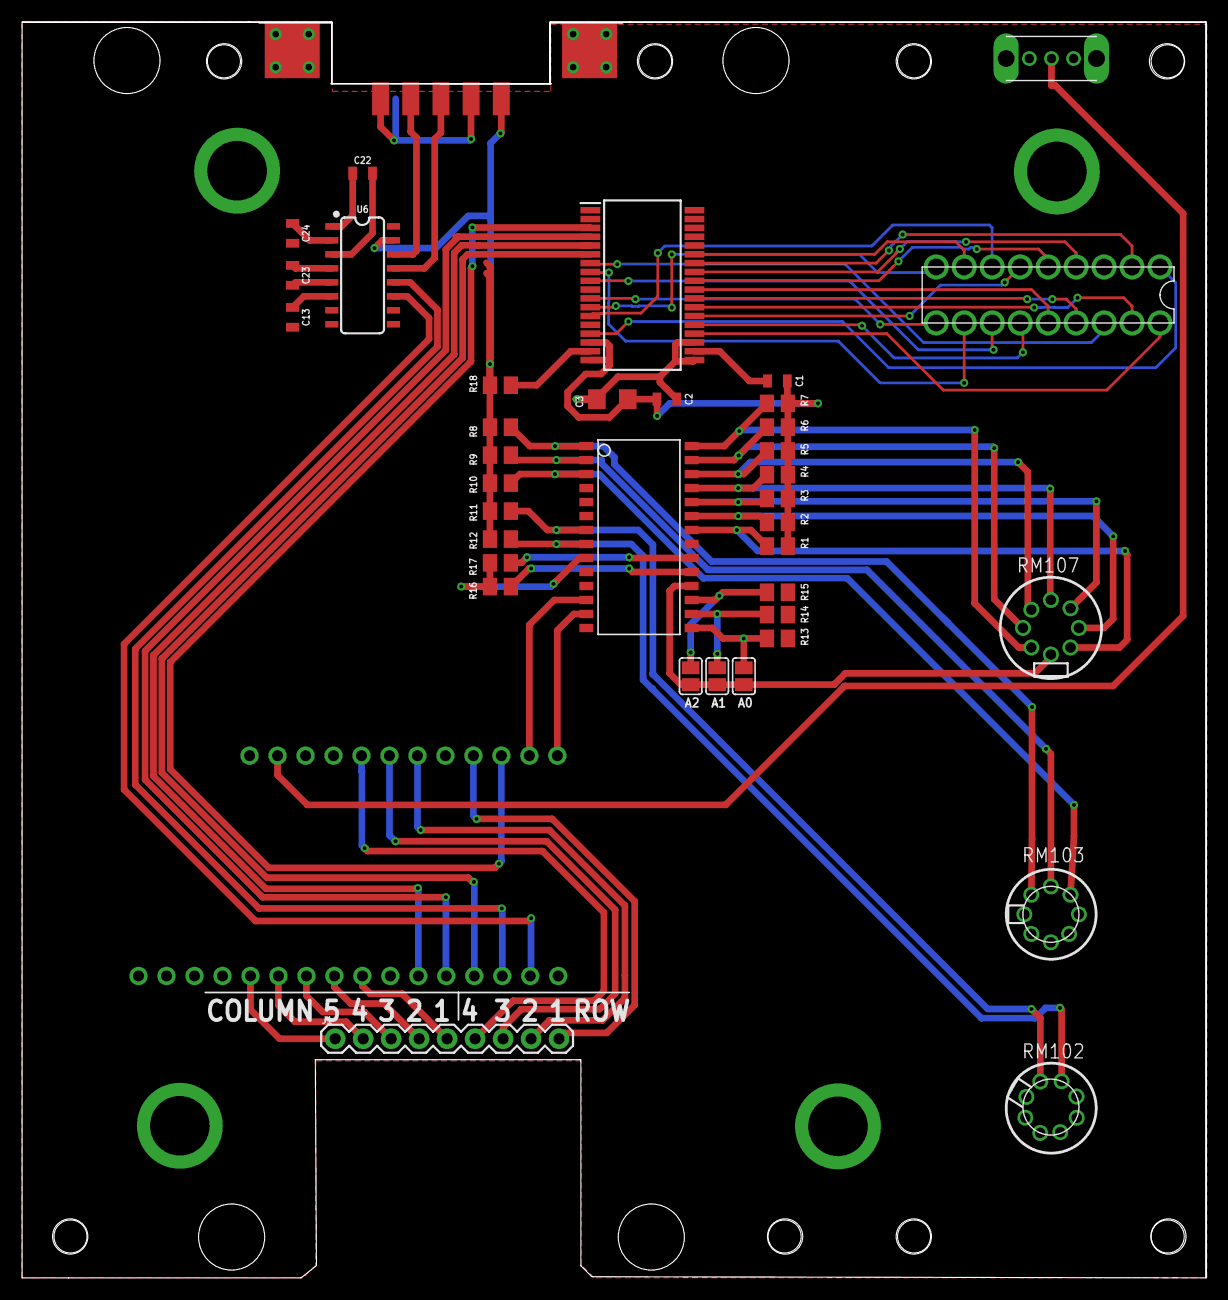
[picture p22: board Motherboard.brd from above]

Board: 2 copper layers, 107.5 x 114.0 mm, 44 parts (1 on the bottom side), 65 nets.

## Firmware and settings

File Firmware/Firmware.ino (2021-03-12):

#include <Wire.h>
#include <Adafruit_Keypad.h>
#include <Adafruit_Keypad_Ringbuffer.h>
#include <Adafruit_GFX.h>
#include "Adafruit_LEDBackpack.h"
#include "Adafruit_MCP23017.h"

const byte ROWS = 4;
const byte COLS = 5;

char keys[ROWS][COLS] = {
  {'C','D','E','F','K'},
  {'8','9','A','B','T'},
  {'4','5','6','7',   },
  {'0','1','2','3',   }
};
byte rowPins[ROWS] = {6,10,11,12};
byte colPins[COLS] = {18,17,16,15,14};

Adafruit_AlphaNum4 alpha = Adafruit_AlphaNum4();
Adafruit_Keypad keypad = Adafruit_Keypad(makeKeymap(keys), rowPins, colPins, ROWS, COLS);

Adafruit_MCP23017 mcp;


int value = NULL;

void setup()
{
  keypad.begin();
  alpha.begin(0x70);
}

void loop() 
{
  keypad.tick();

  KeypadLoop();
  delay(40);
}

void SetupSerial(void)
{
  /*  
  int mcpPins[] = {1,2,3,4,5,6,7,8,9,10,14,15};
  long baudValue[] = {115200,57600,19200,9600,2400,1200,300};
  char parityValue[] = {'N','E','O'};

  long baudRate;
  char parity;
  int stopBit = 1;
  
  mcp.begin();
  mcp.pinMode(1, INPUT);
  mcp.pinMode(2, INPUT);
  mcp.pinMode(3, INPUT);
  mcp.pinMode(4, INPUT);
  mcp.pinMode(5, INPUT);
  mcp.pinMode(6, INPUT);
  mcp.pinMode(7, INPUT);
  mcp.pinMode(8, INPUT);
  mcp.pinMode(9, INPUT);
  mcp.pinMode(10, INPUT);
  mcp.pinMode(14, INPUT);
  mcp.pinMode(15, INPUT);
  
  mcp.pullUp(1, HIGH);
  mcp.pullUp(2, HIGH);
  mcp.pullUp(3, HIGH);
  mcp.pullUp(4, HIGH);
  mcp.pullUp(5, HIGH);
  mcp.pullUp(6, HIGH);
  mcp.pullUp(7, HIGH);
  mcp.pullUp(8, HIGH);
  mcp.pullUp(9, HIGH);
  mcp.pullUp(10, HIGH);
  mcp.pullUp(14, HIGH);
  mcp.pullUp(15, HIGH);


  //read the baud rate dial
  for(int i = 0 ; i < 7 ; i++)
  {
    if(mcp.digitalRead(mcpPins[i]) == HIGH)
      baudRate = baudValue[i];
  }

  //read the parity
  for(int i = 7 ; i < 10 ; i++)
  {
    if(mcp.digitalRead(mcpPins[i]) == HIGH)
      parity = parityValue[(i-7)];
  }

  //read the stop bits
  if(mcp.digitalRead(14) == HIGH)
    stopBit = 1;
  else
    stopBit = 2;
    
  //put it all together
  if(stopBit == 1 && parity == 'N')
    Serial1.begin(baudRate, SERIAL_8N1);
  else if(stopBit == 1 && parity == 'E')
    Serial1.begin(baudRate, SERIAL_8E1);
  else if(stopBit == 1 && parity == 'O')
    Serial1.begin(baudRate, SERIAL_8O1);
  else if(stopBit == 2 && parity == 'N')
    Serial1.begin(baudRate, SERIAL_8N2);
  else if(stopBit == 2 && parity == 'E')
    Serial1.begin(baudRate, SERIAL_8E2);
  else if(stopBit == 2 && parity == 'O')
    Serial1.begin(baudRate, SERIAL_8O2);

  //comment the below lines out when you're done testing
  Serial.begin(9600);
  Serial.print("Baud: ");
  Serial.print(baudRate);
  Serial.print(" Parity: ");
  Serial.print(parity);
  Serial.print(" Stop: ");
  Serial.print(stopBit);
  Serial.print("  \n\r");
  */

  Serial1.begin(9600);
}

void TransmitValue(int value)
{
  SetupSerial();
  Serial1.print(char(value));

  //Serial1.end();
}

void KeypadLoop(void)
{
    char currentKey;  
  
    while(keypad.available())
  {
    keypadEvent e = keypad.read();
    if(e.bit.EVENT == KEY_JUST_PRESSED) 
    {
      currentKey = (char)e.bit.KEY;
    }

    if(value == NULL)
    {
      switch(currentKey)
      {
        case '0':
          value = 0;
        break;
        case '1':
          value = 1;
        break;
        case '2':
          value = 2;
        break;
        case '3':
          value = 3;
        break;
        case '4':
          value = 4;
        break;
        case '5':
          value = 5;
        break;
        case '6':
          value = 6;
        break;
        case '7':
          value = 7;
        break;
        case '8':
          value = 8;
        break;
        case '9':
          value = 9;
        break;
        case 'A':
          value = 10;
        break;
        case 'B':
          value = 11;
        break;
        case 'C':
          value = 12;
        break;
        case 'D':
          value = 13;
        break;
        case 'E':
          value = 14;
        break;
        case 'F':
          value = 15;
        break;
      }
    }
    else
    {
      switch(currentKey)
      {
        case '0':
          value = value * 16;
        break;
        case '1':
          value = value * 16 + 1;
        break;
        case '2':
          value = value * 16 + 2;
        break;
        case '3':
          value = value * 16 + 3;
        break;
        case '4':
          value = value * 16 + 4;
        break;
        case '5':
          value = value * 16 + 5;
        break;
        case '6':
          value = value * 16 + 6;
        break;
        case '7':
          value = value * 16 + 7;
        break;
        case '8':
          value = value * 16 + 8;
        break;
        case '9':
          value = value * 16 + 9;
        break;
        case 'A':
          value = value * 16 + 10;
        break;
        case 'B':
          value = value * 16 + 11;
        break;
        case 'C':
          value = value * 16 + 12;
        break;
        case 'D':
          value = value * 16 + 13;
        break;
        case 'E':
          value = value * 16 + 14;
        break;
        case 'F':
          value = value * 16 + 15;
        break;
        case 'K':
          value = NULL;
        break;
        case 'T':
          TransmitValue(value);
          value = NULL;
        break;
         
        }
      }
      WriteToDisplay(value);
    }
}

void WriteToDisplay(int value)
{
  if(value == NULL)
  {
    alpha.writeDigitAscii(0, 0xFF);
    alpha.writeDigitAscii(1, 0xFF);
  }
  else
  {
        String hexString = String(value, HEX);
        hexString.toUpperCase();
        alpha.writeDigitAscii(0, hexString[0]);
        if(hexString[1] == NULL)
        {
          alpha.writeDigitAscii(1, hexString[0]);
          alpha.writeDigitAscii(0, '0');
        }
        else
        {
          alpha.writeDigitAscii(0, hexString[0]);
          alpha.writeDigitAscii(1, hexString[1]);
        }
  }
  alpha.writeDisplay();
}

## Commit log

2020-12-28 I think I got this taken care of
    [BigKnob.stl, Bottom.stl, DisplayCarrier.brd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]
2021-02-01 well it works now
    [BigKnob.stl, Motherboard.sch, MotherboardThin.sch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]
2021-03-12 Added renders, readme, cleanup
    [MasterBoard.brd, MasterBoard.sch]

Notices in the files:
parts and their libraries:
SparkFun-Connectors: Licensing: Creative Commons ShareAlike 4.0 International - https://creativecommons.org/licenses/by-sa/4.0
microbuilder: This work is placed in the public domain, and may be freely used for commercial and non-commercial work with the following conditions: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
